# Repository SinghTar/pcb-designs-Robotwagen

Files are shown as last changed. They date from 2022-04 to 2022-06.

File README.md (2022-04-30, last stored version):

# PCB designs

## Linetrackerboard versie 1

Hieronder vindt u de schema en de pcb design van de linetrackerbordje.

### schema 

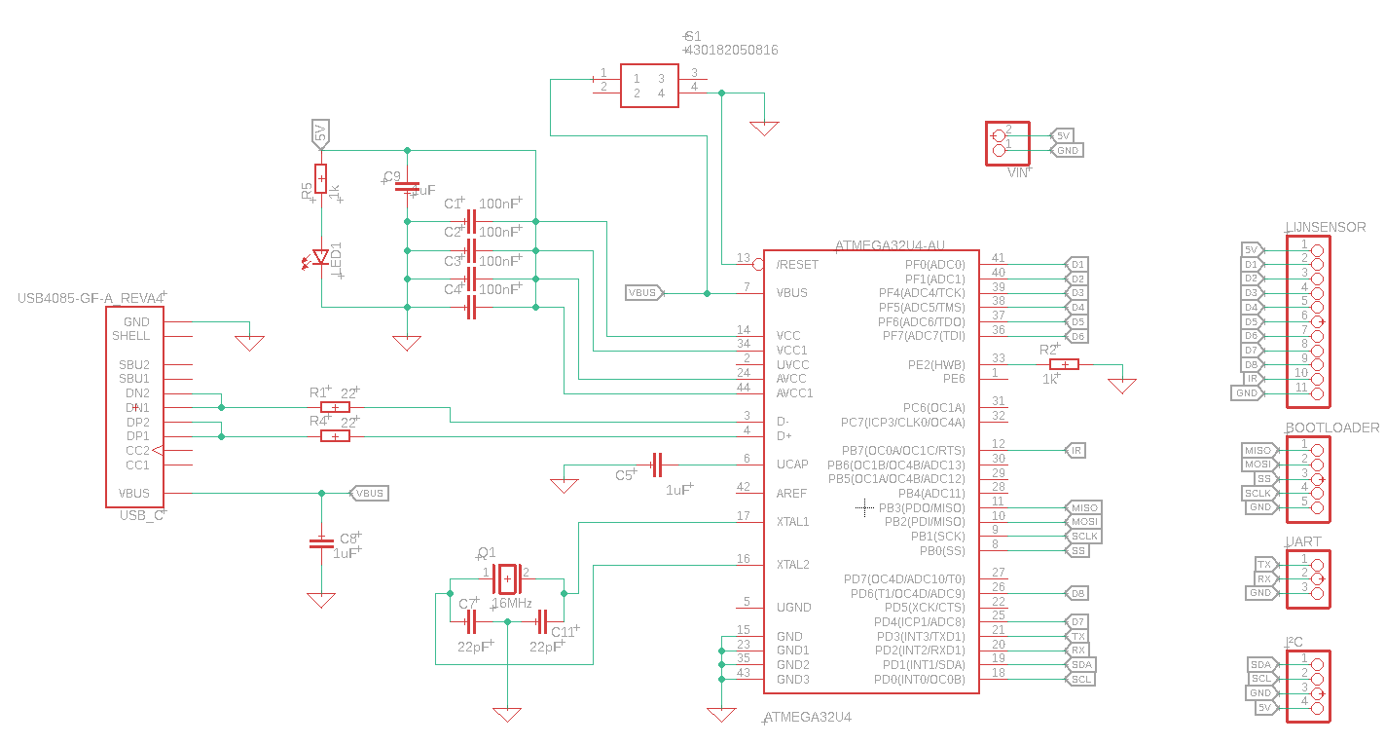
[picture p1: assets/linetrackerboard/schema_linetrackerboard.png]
schema linetrackerboard


### pcb

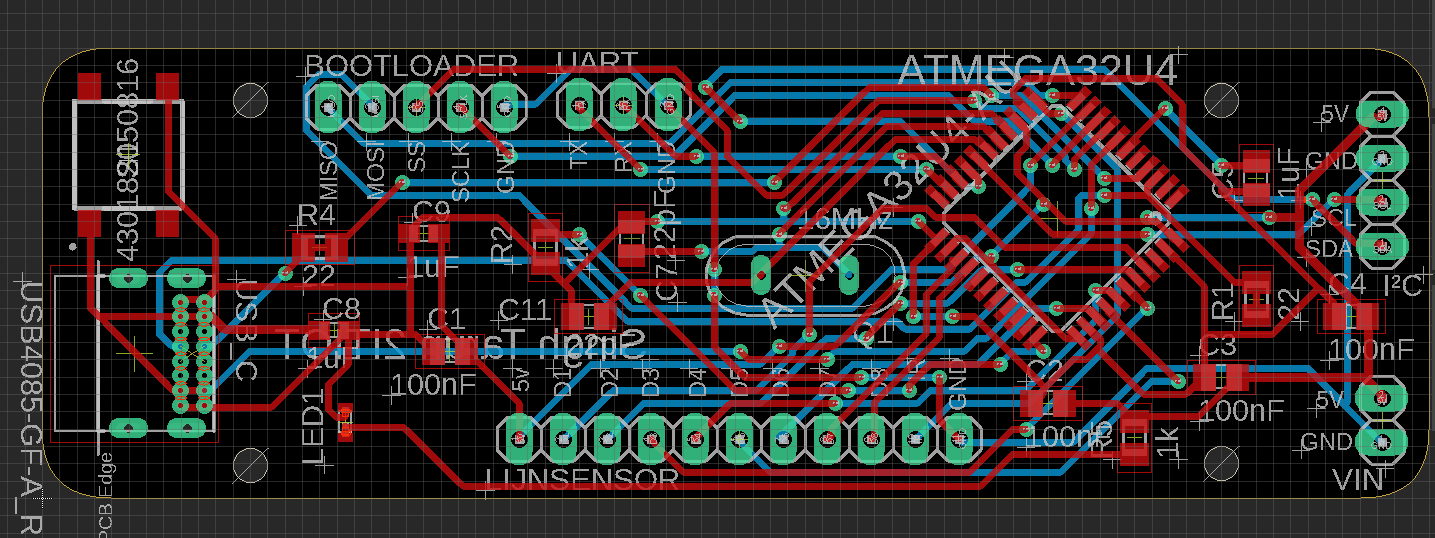
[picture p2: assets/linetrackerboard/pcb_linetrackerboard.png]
pcb linetrackerboard


### 3D design

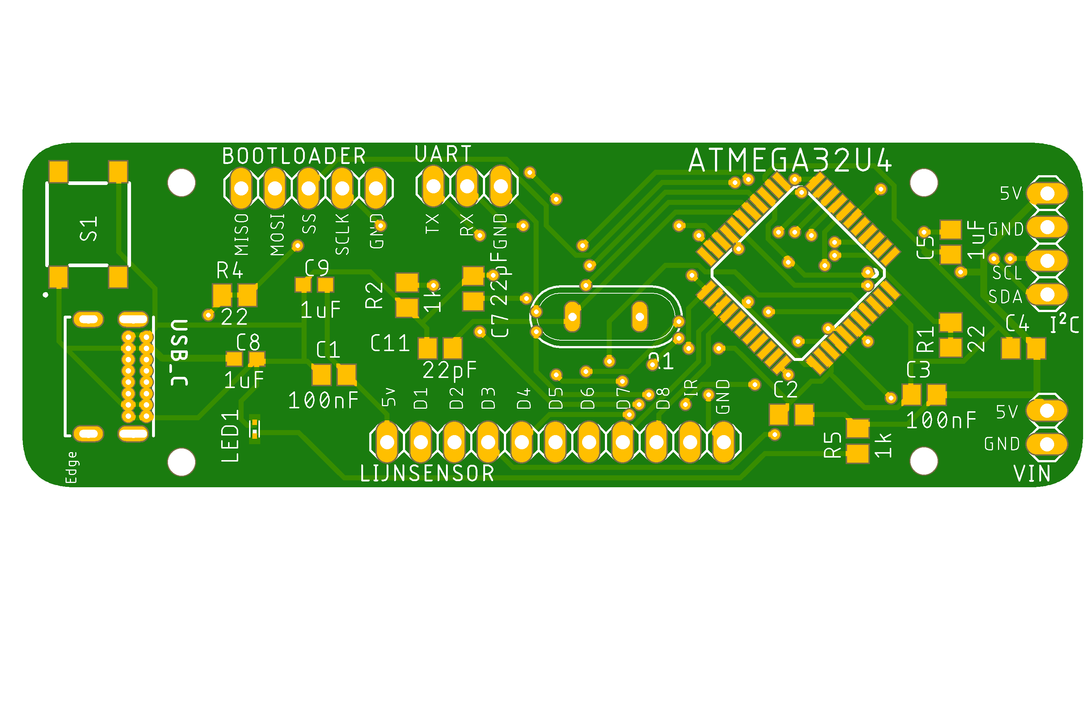
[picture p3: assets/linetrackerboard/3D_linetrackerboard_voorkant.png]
3D voorkant van linetrackerboard


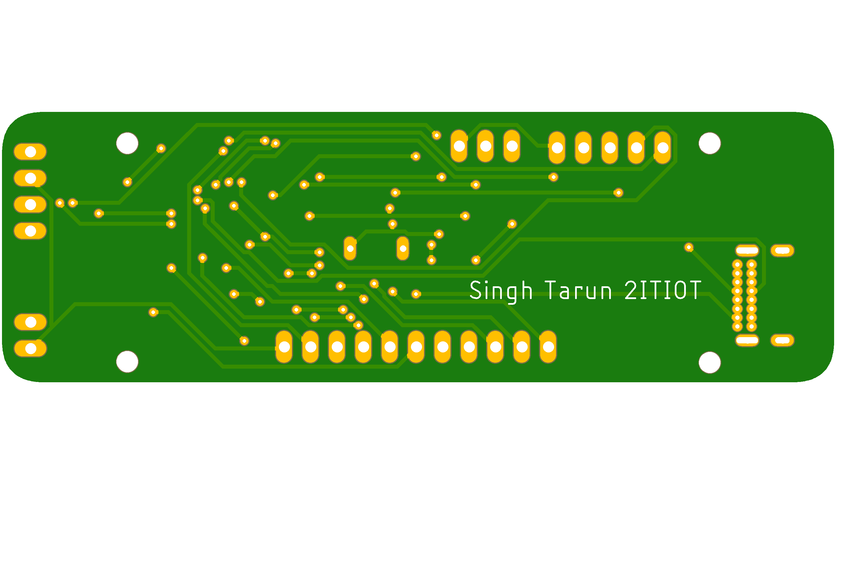
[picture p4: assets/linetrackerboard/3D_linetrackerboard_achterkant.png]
3D achterkant van linetrackerboard


## Motorsturing versie 1

Hieronder vindt u de schema en de pcb design van de motorsturing.

### schema 

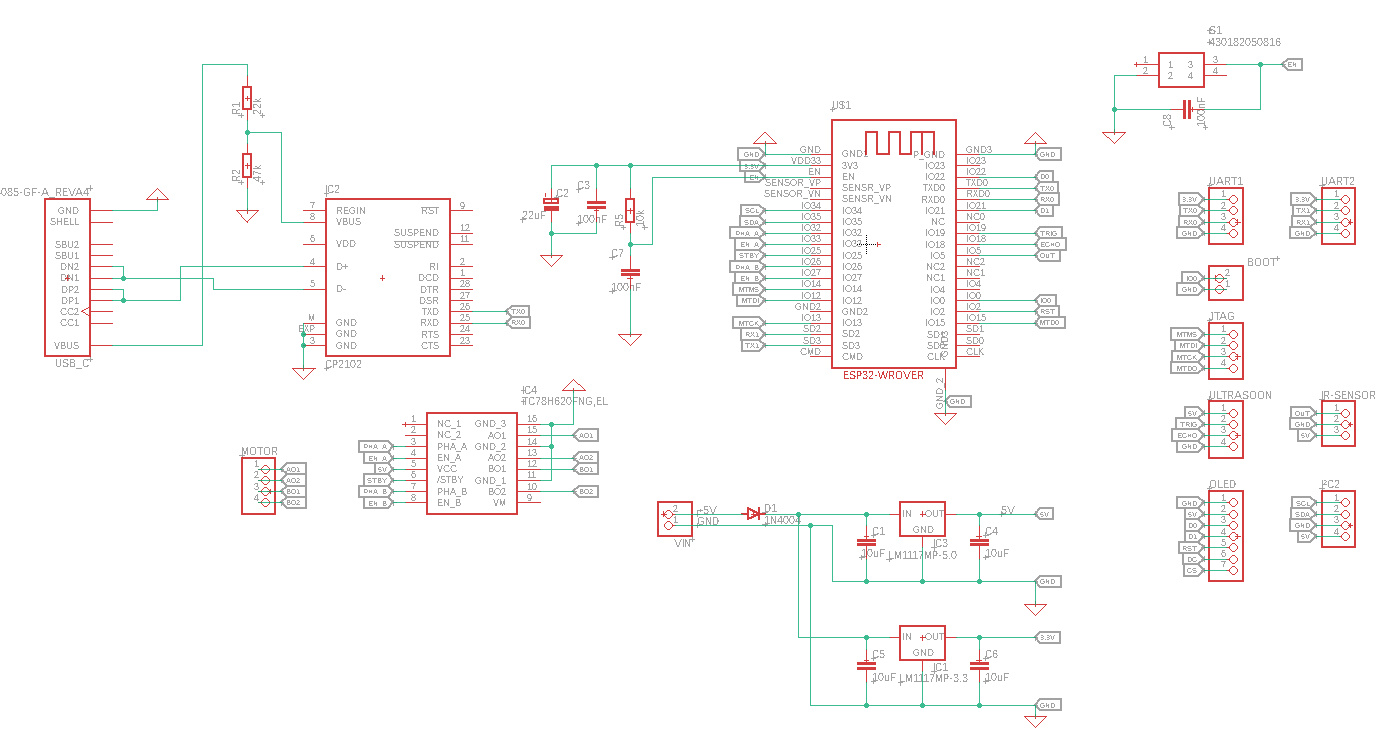
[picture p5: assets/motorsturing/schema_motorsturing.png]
schema motorsturing


### pcb

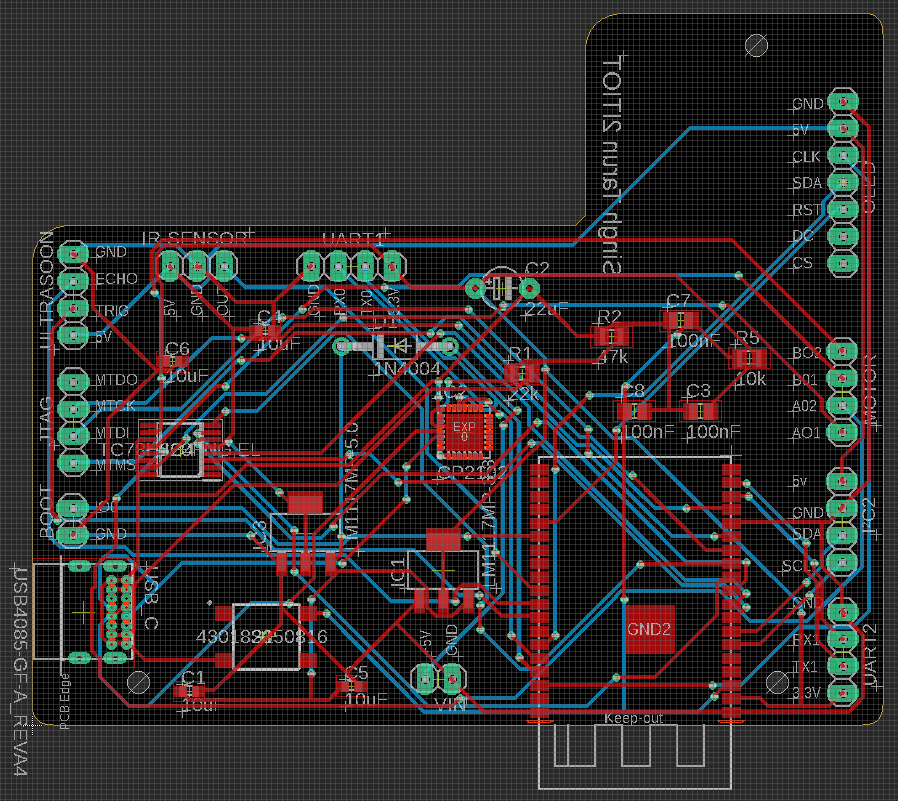
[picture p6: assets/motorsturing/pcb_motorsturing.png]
pcb motorsturing


### 3D design

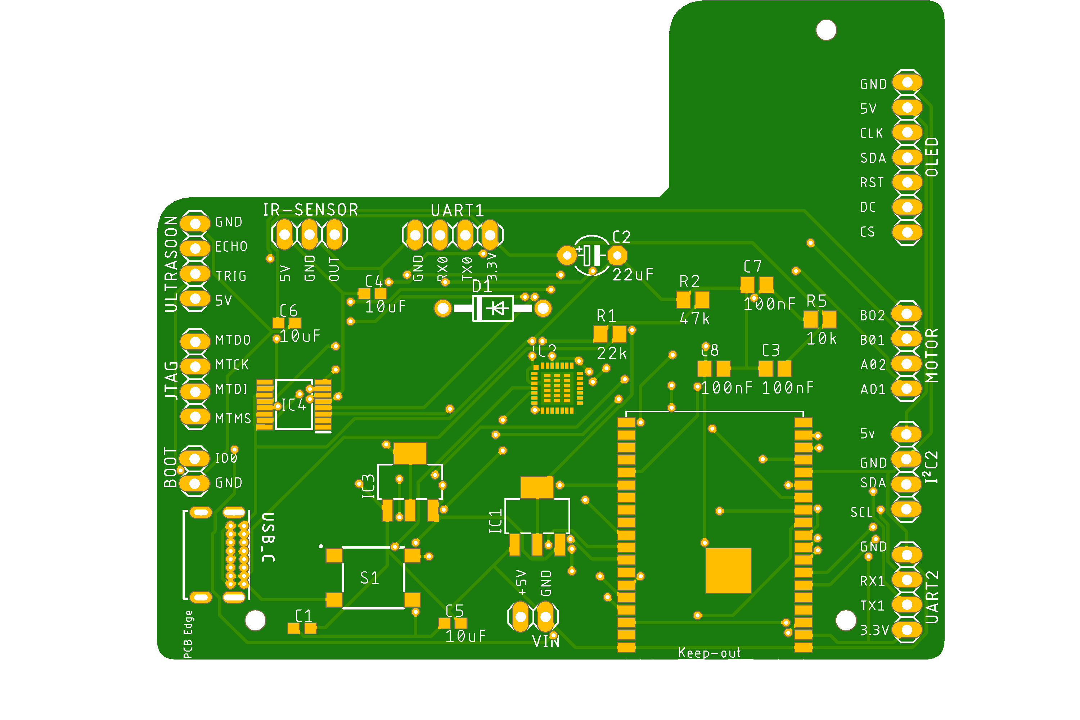
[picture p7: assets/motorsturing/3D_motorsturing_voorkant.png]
3D voorkant van motorsturing


3D achterkant van motorsturing

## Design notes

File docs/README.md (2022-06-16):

# PCB designs

## Linetrackerboard

### Versie 1

Hieronder vindt u de schema en de pcb design van de linetrackerbordje.

#### schema 

schema linetrackerboard

#### pcb

pcb linetrackerboard

#### 3D design

3D voorkant van linetrackerboard

3D achterkant van linetrackerboard

### Versie 2

Hieronder vindt u de schema en de pcb design van de linetrackerbordje.

#### schema 

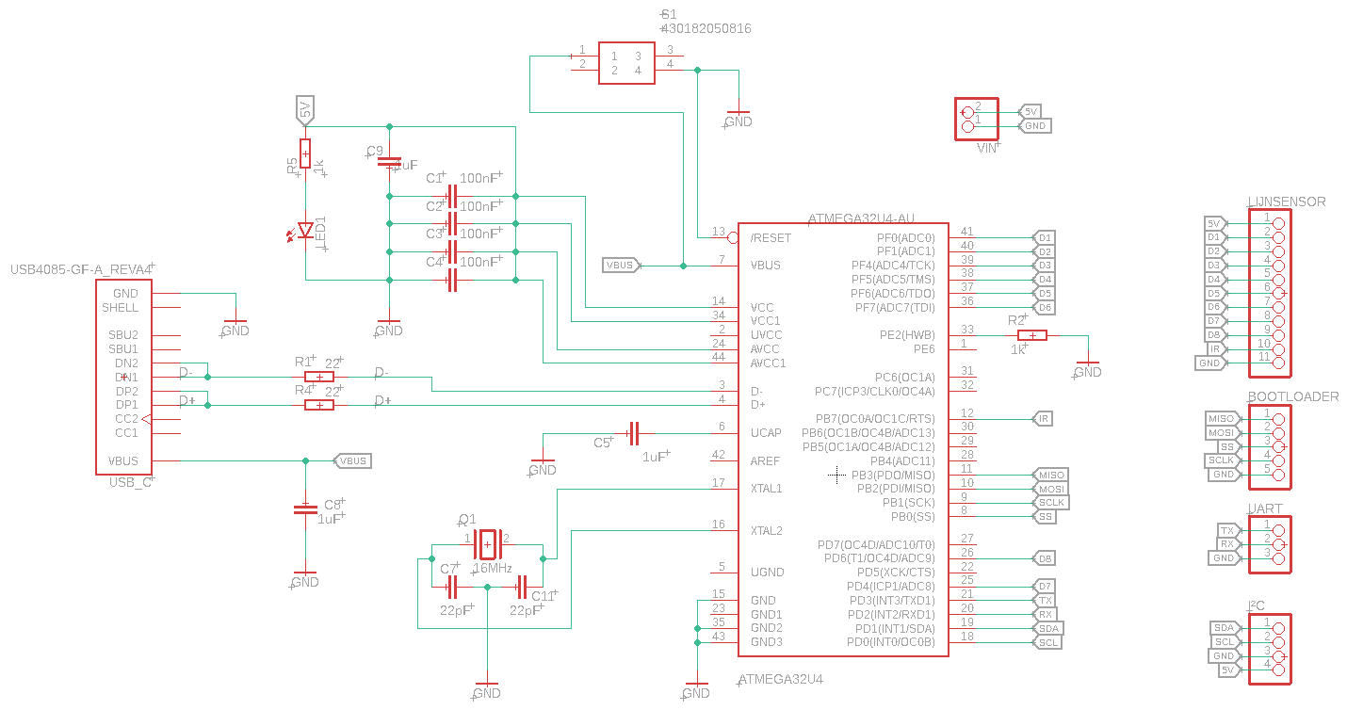
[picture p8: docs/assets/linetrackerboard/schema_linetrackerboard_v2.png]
schema linetrackerboard


#### pcb

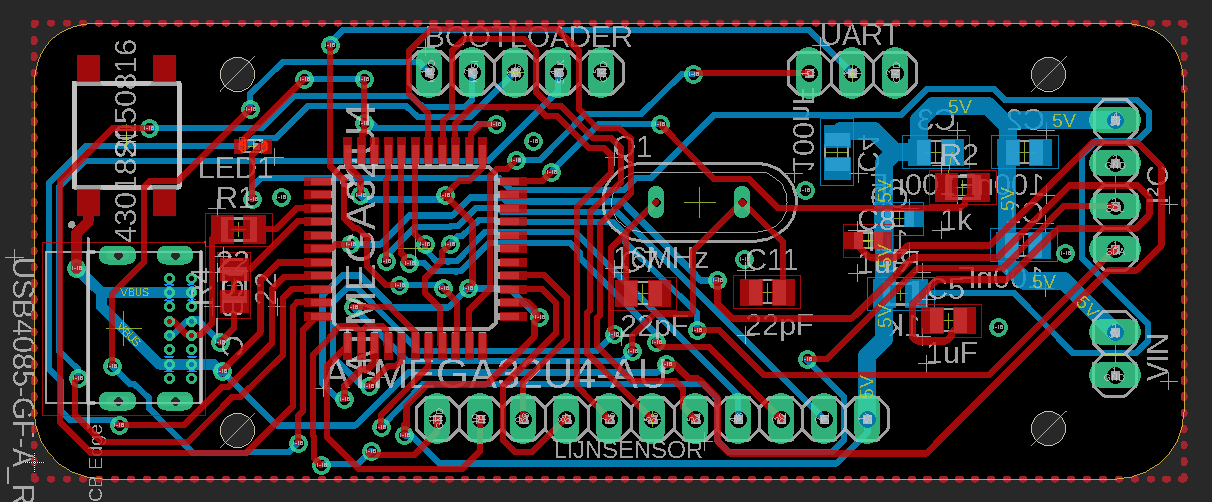
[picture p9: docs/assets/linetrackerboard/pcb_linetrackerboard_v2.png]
pcb linetrackerboard


#### 3D design

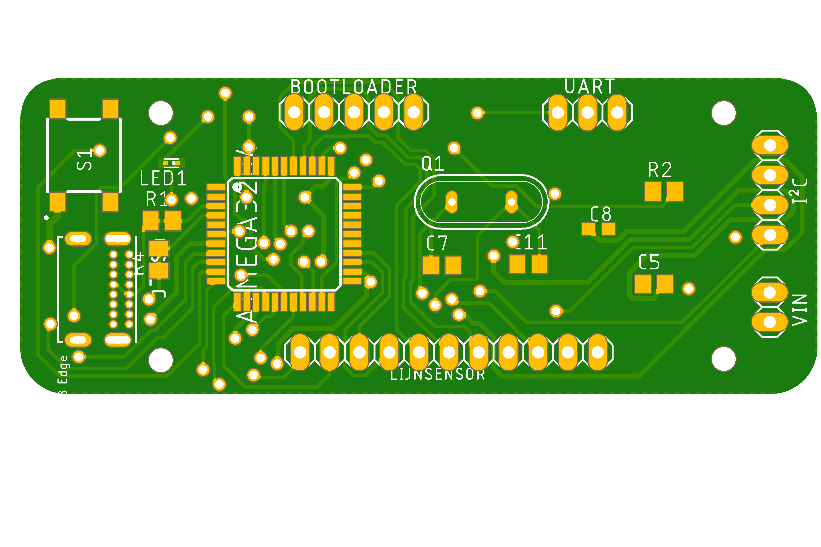
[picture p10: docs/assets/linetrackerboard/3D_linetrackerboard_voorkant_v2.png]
3D voorkant van linetrackerboard


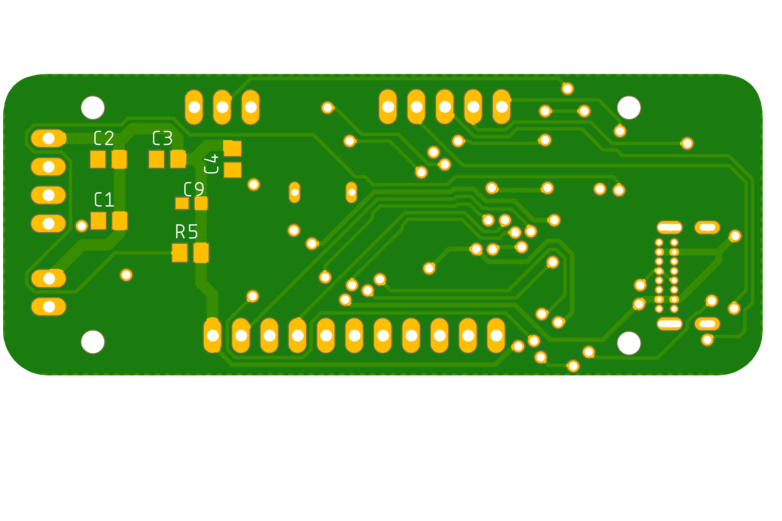
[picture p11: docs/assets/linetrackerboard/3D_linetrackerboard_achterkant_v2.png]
3D achterkant van linetrackerboard


## Motorsturing

### versie 1

Hieronder vindt u de schema en de pcb design van de motorsturing.

#### schema 

schema motorsturing

#### pcb

pcb motorsturing

#### 3D design

3D voorkant van motorsturing

3D achterkant van motorsturing

### versie 2

Hieronder vindt u de schema en de pcb design van de motorsturing.

#### schema 

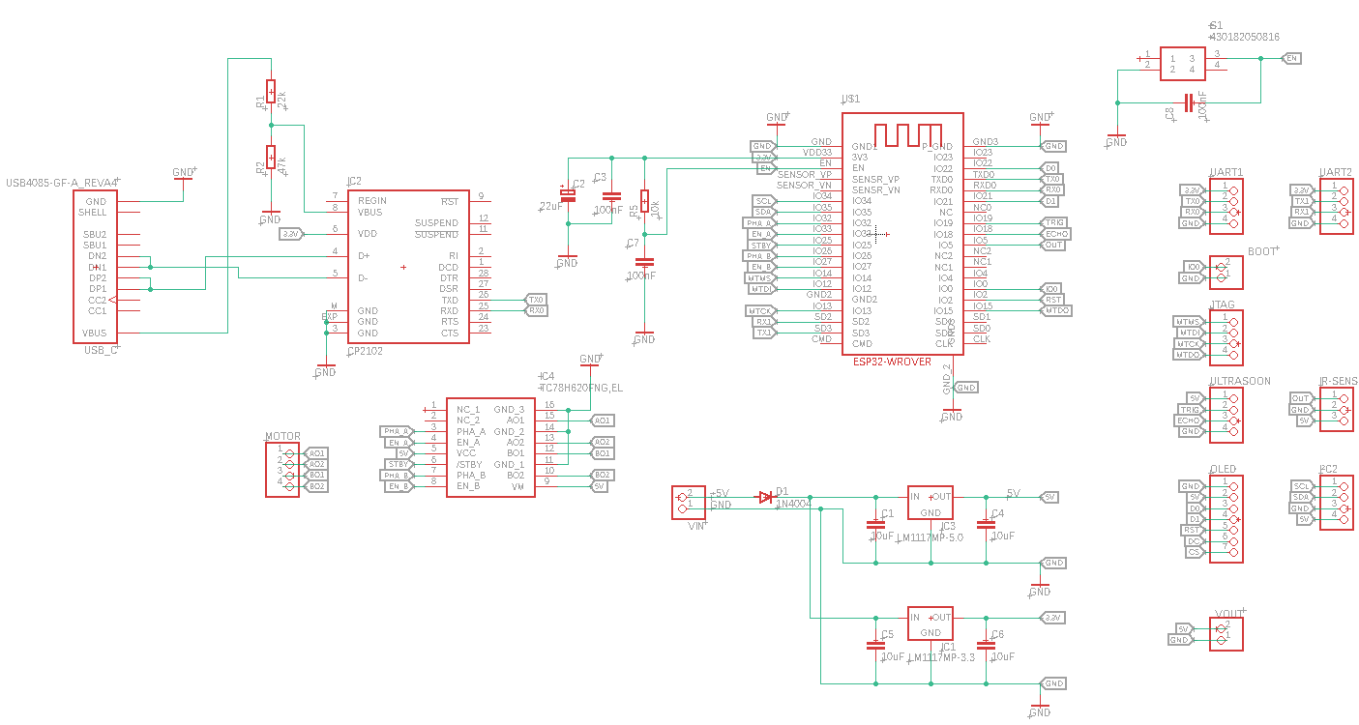
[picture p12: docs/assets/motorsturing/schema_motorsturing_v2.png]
schema motorsturing


#### pcb

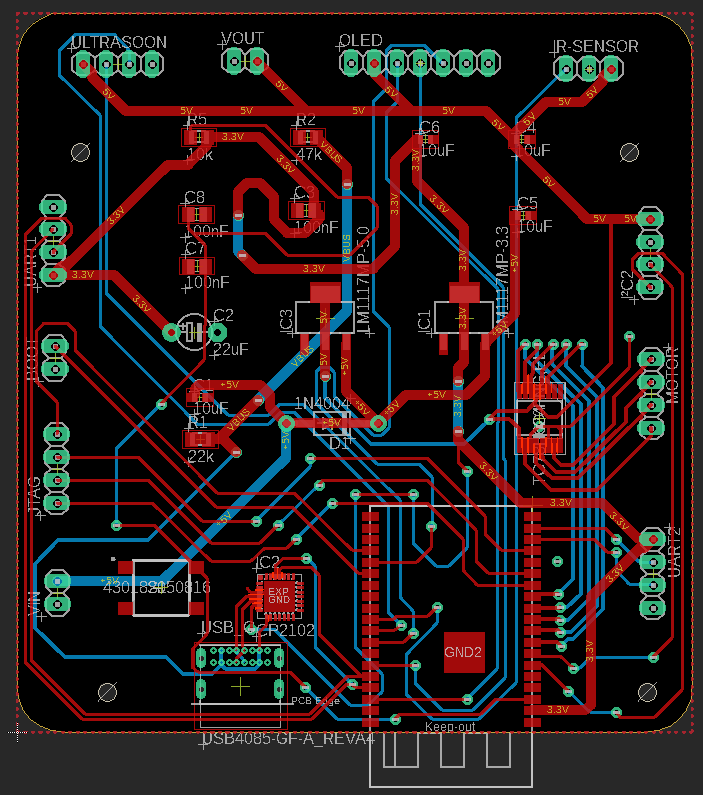
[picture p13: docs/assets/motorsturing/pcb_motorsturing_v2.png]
pcb motorsturing


#### 3D design

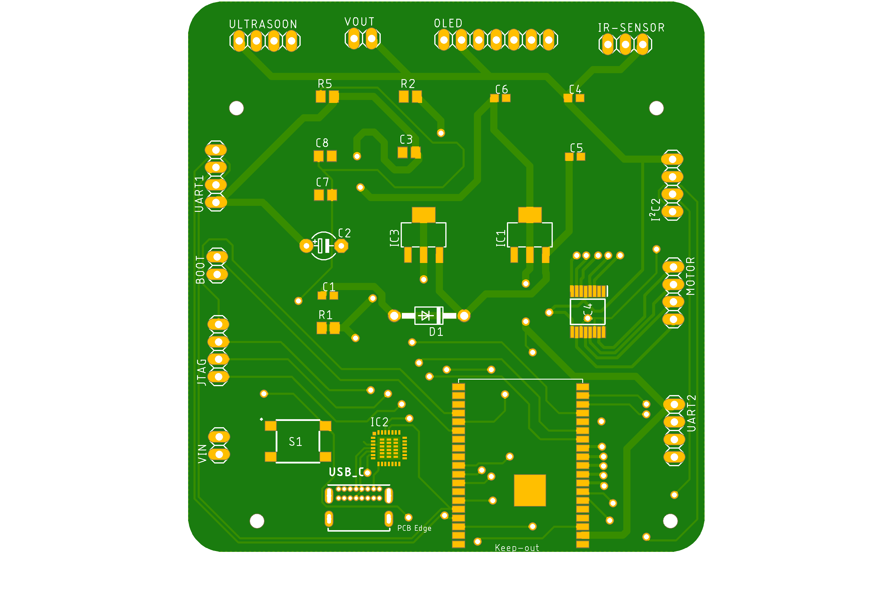
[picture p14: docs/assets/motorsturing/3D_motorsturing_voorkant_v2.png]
3D voorkant van motorsturing


3D achterkant van motorsturing

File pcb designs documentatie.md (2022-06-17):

# Externe link naar de pcb designs

[pcb designs robotwagen](https://singhtar.github.io/pcb-designs-Robotwagen/#/)

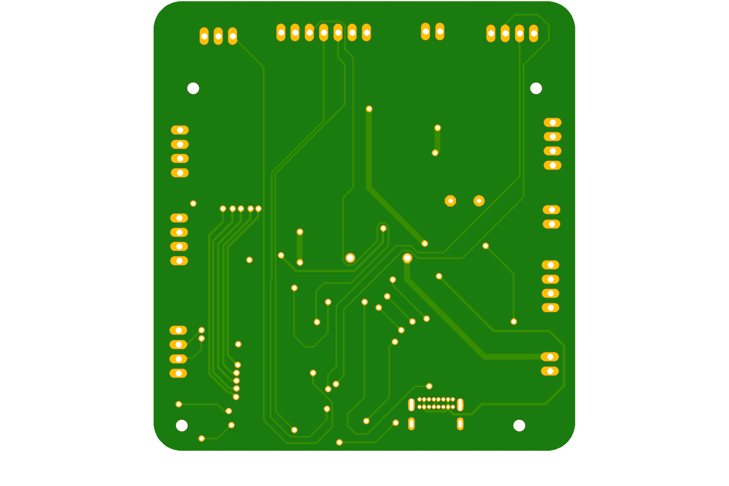
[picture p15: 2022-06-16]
docs/assets/motorsturing/3D_motorsturing_achterkant_v2.png

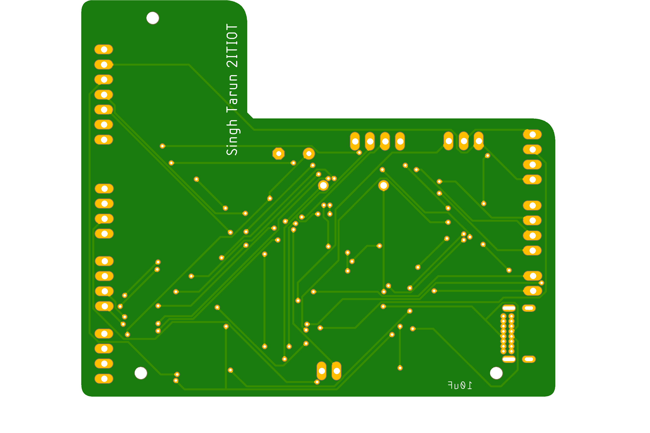
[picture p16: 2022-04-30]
docs/assets/motorsturing/3D_motorsturing_achterkant_v1.png

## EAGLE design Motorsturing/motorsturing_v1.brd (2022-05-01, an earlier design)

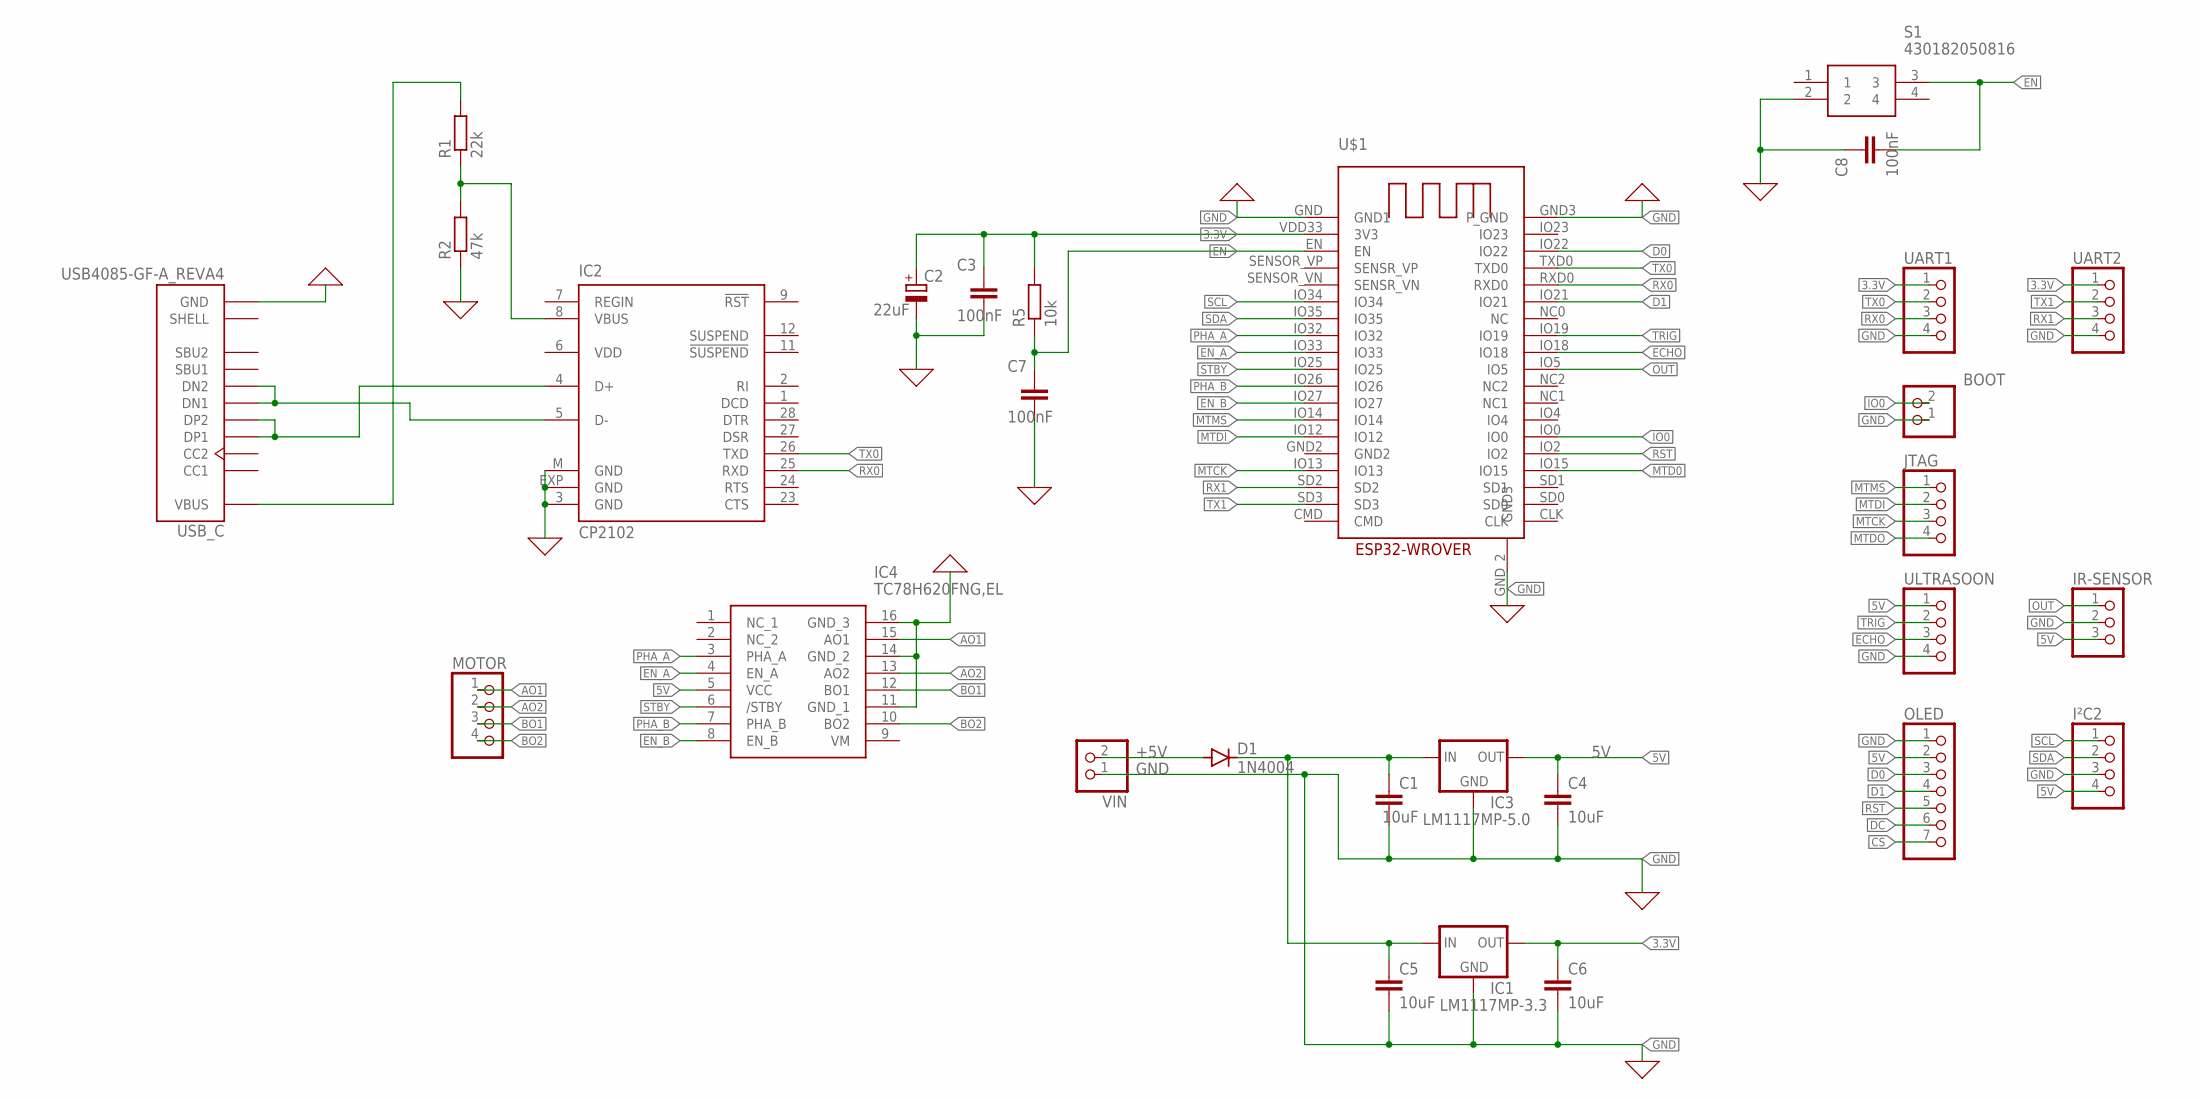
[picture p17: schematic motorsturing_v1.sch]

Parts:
BOOT: PINHD-1X2; 1X02
C1, C4, C5, C6: 10uF; C0603
C2: 22uF; E5-4
C3, C7, C8: 100nF; C0805
D1: 1N4004; DO41-10
IC1: LM1117MP-3.3; SOT223
IC2: CP2102; MLP28
IC3: LM1117MP-5.0; SOT223
IC4: TC78H620FNG,EL; SOP65P640X160-16N
IR-SENSOR: PINHD-1X3; 1X03
I²C2: PINHD-1X4; 1X04
JTAG: PINHD-1X4; 1X04
MOTOR: PINHD-1X4; 1X04
OLED: PINHD-1X7; 1X07
R1: 22k; M0805
R2: 47k; M0805
R5: 10k; M0805
S1: 430182050816; 430182070816
U$1: ESP32-WROVER
UART1, UART2: PINHD-1X4; 1X04
ULTRASOON: PINHD-1X4; 1X04
USB_C: USB4085-GF-A_REVA4; GCT_USB4085-GF-A_REVA4
VIN: PINHD-1X2; 1X02

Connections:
0: C2.-, C3.1, C7.1, C8.2, IC2.3 (GND), IC2.EXP (GND), IC2.M (GND), IC4.11 (GND_1), IC4.14 (GND_2), IC4.16 (GND_3), R2.1, S1.2, USB_C.A1 (GND), USB_C.A12 (GND), USB_C.B1 (GND), USB_C.B12 (GND)
3.3V: C2.+, C3.2, C6.1, IC1.2 (OUT), IC1.4 (OUT), R5.2, U$1.VDD33 (3V3), UART1.1, UART2.1
5V: C4.1, IC3.2 (OUT), IC3.4 (OUT), IC4.5 (VCC), IR-SENSOR.3, I²C2.4, OLED.2, ULTRASOON.1
+5V: D1.A, VIN.2
AO1: IC4.15 (AO1), MOTOR.1
AO2: IC4.13 (AO2), MOTOR.2
BO1: IC4.12 (BO1), MOTOR.3
BO2: IC4.10 (BO2), MOTOR.4
CS: OLED.7
D0: OLED.3, U$1.IO22
D1: OLED.4, U$1.IO21
DC: OLED.6
ECHO: U$1.IO18, ULTRASOON.3
EN: C7.2, C8.1, R5.1, S1.3, U$1.EN
EN_A: IC4.4 (EN_A), U$1.IO33
EN_B: IC4.8 (EN_B), U$1.IO27
GND: BOOT.1, C1.2, C4.2, C5.2, C6.2, IC1.1 (GND), IC3.1 (GND), IR-SENSOR.2, I²C2.3, OLED.1, U$1.GND (GND1), U$1.GND3 (P_GND), U$1.GND_2 (GND3), UART1.4, UART2.4, ULTRASOON.4, VIN.1
IO0: BOOT.2, U$1.IO0
MTCK: JTAG.3, U$1.IO13
MTD0: U$1.IO15
MTDI: JTAG.2, U$1.IO12
MTDO: JTAG.4
MTMS: JTAG.1, U$1.IO14
unnamed: IC2.5 (D-), USB_C.A7 (DN1), USB_C.B7 (DN2)
unnamed: IC2.4 (D+), USB_C.A6 (DP1), USB_C.B6 (DP2)
unnamed: R1.2, USB_C.A4 (VBUS), USB_C.A9 (VBUS), USB_C.B4 (VBUS), USB_C.B9 (VBUS)
unnamed: IC2.8 (VBUS), R1.1, R2.2
unnamed: C1.1, C5.1, D1.C, IC1.3 (IN), IC3.3 (IN)
OUT: IR-SENSOR.1, U$1.IO5
PHA_A: IC4.3 (PHA_A), U$1.IO32
PHA_B: IC4.7 (PHA_B), U$1.IO26
RST: OLED.5, U$1.IO2
RX0: IC2.25 (RXD), U$1.RXD0, UART1.3
RX1: U$1.SD2, UART2.3
SCL: I²C2.1, U$1.IO34
SDA: I²C2.2, U$1.IO35
STBY: IC4.6 (/STBY), U$1.IO25
TRIG: U$1.IO19, ULTRASOON.2
TX0: IC2.26 (TXD), U$1.TXD0, UART1.2
TX1: U$1.SD3, UART2.2
VDD: IC2.6 (VDD)

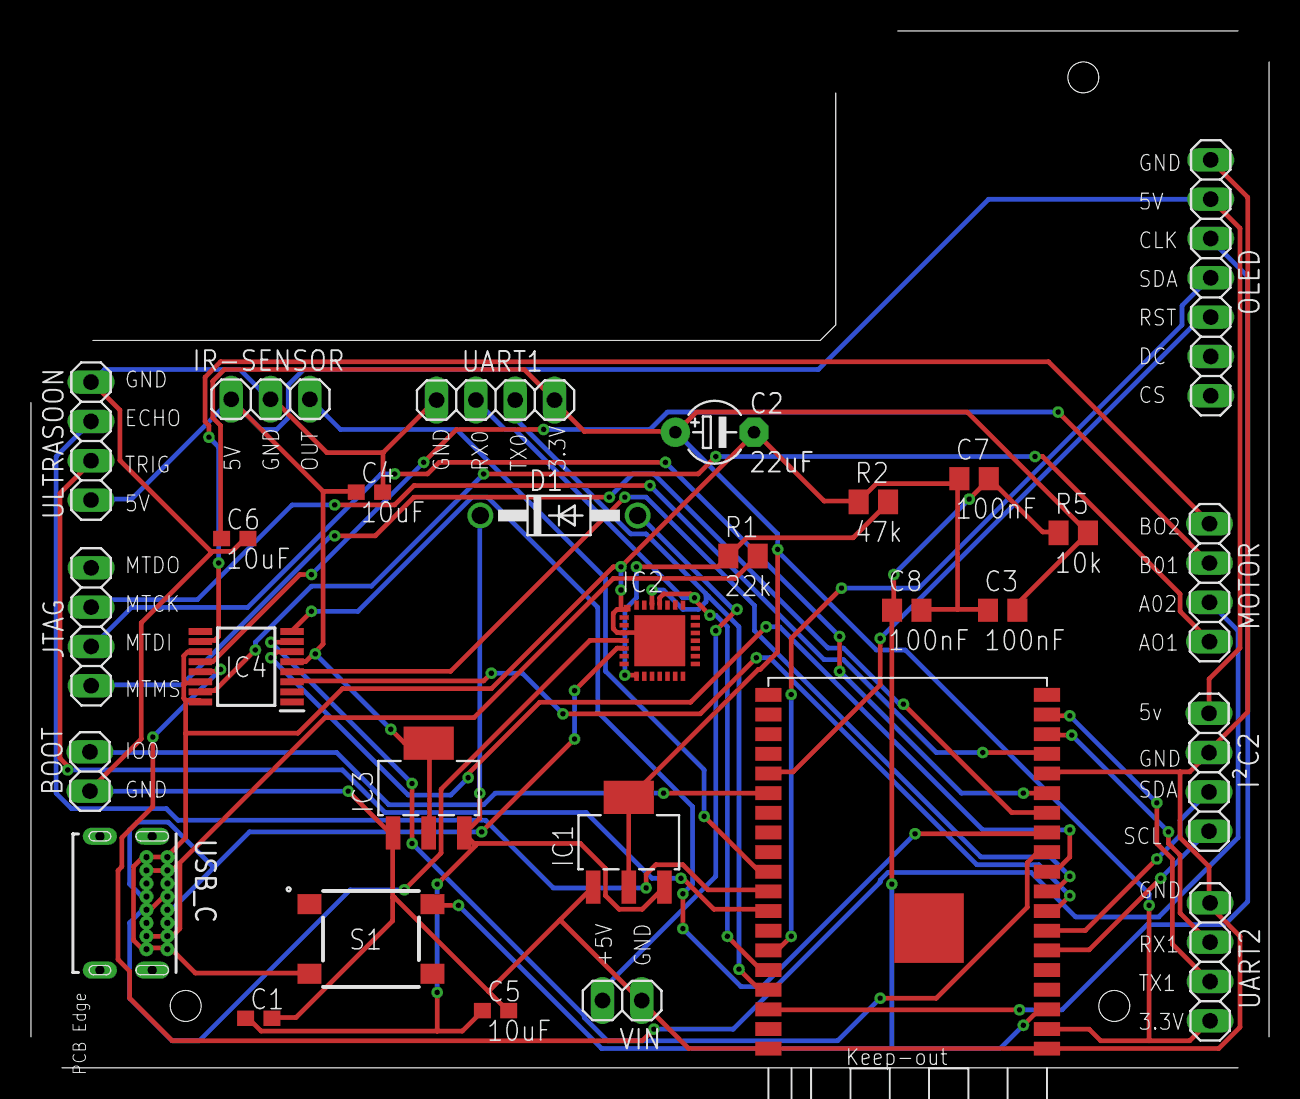
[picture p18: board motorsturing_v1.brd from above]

Board: 2 copper layers, 80.0 x 67.0 mm, 29 parts (0 on the bottom side), 36 nets.

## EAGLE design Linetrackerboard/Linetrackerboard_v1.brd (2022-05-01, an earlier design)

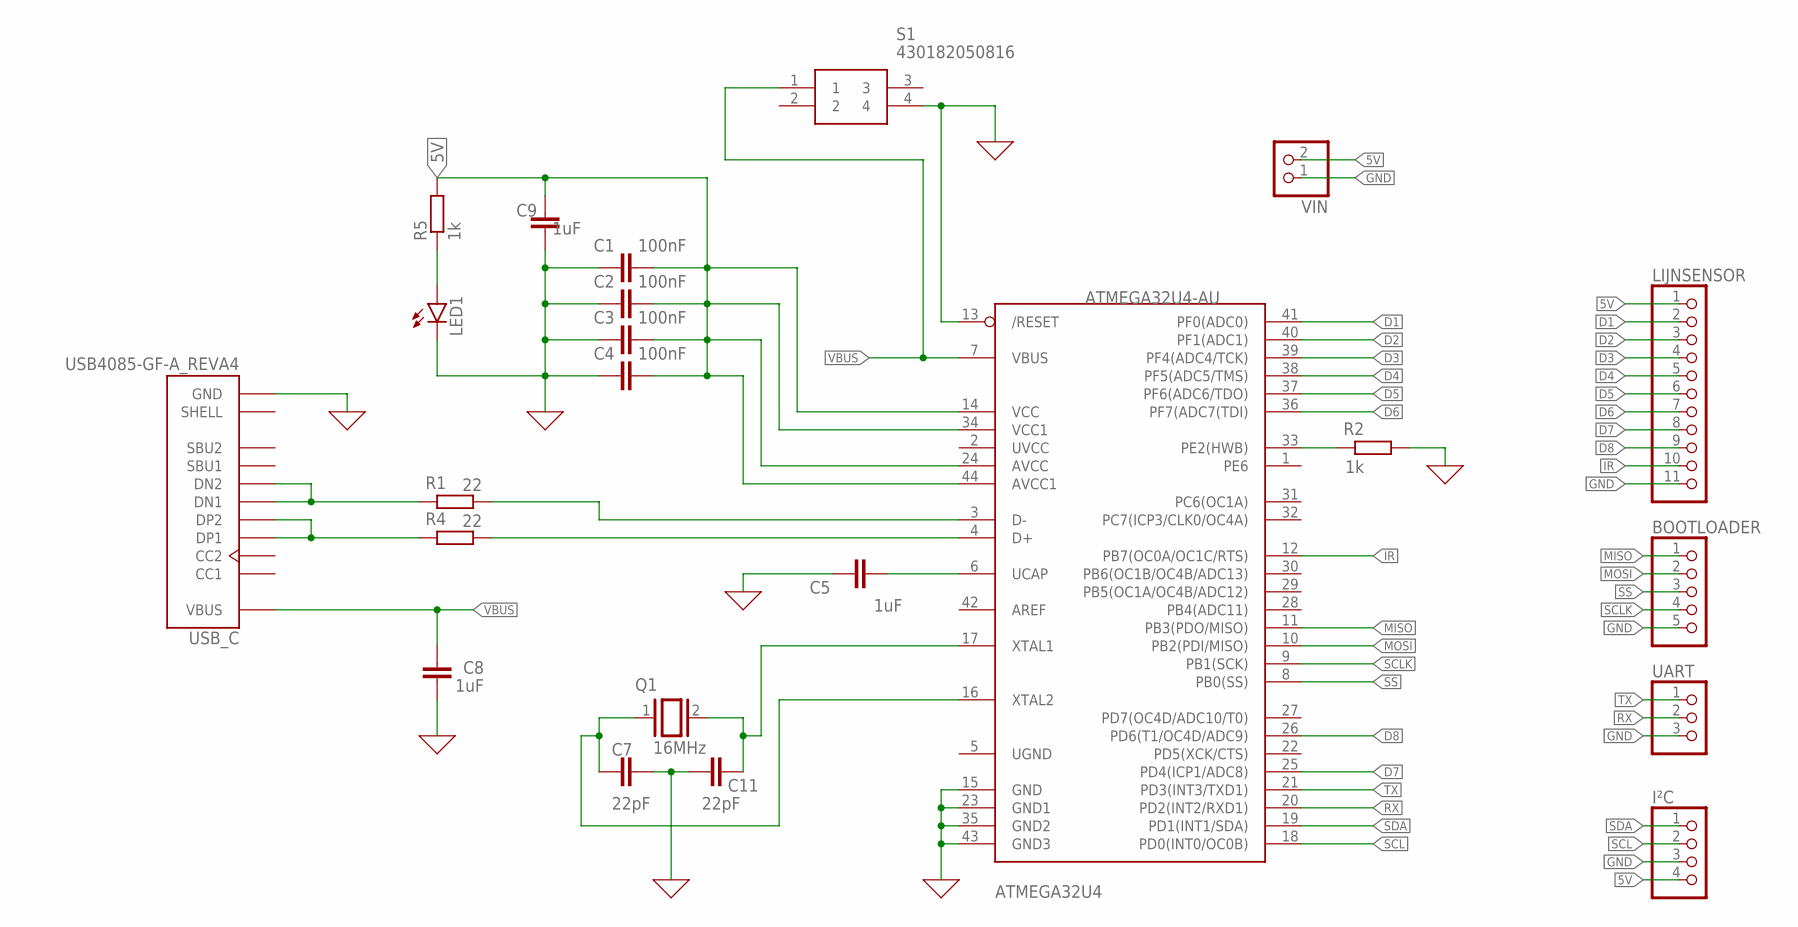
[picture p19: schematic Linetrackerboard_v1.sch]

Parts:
ATMEGA32U4: ATMEGA32U4-AU; TQFP44
BOOTLOADER: PINHD-1X5; 1X05
C1, C2, C3, C4: 100nF; C0805
C5: 1uF; C0805
C7, C11: 22pF; C0805
C8, C9: 1uF; C0603
I²C: PINHD-1X4; 1X04
LED1: LED; SMARTLED-TTW
LIJNSENSOR: PINHD-1X11; 1X11
Q1: 16MHz; QS
R1, R4: 22; M0805
R2, R5: 1k; M0805
S1: 430182050816; 430182070816
UART: PINHD-1X3; 1X03
USB_C: USB4085-GF-A_REVA4; GCT_USB4085-GF-A_REVA4
VIN: PINHD-1X2; 1X02

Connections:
0: ATMEGA32U4.13 (/RESET), ATMEGA32U4.15 (GND), ATMEGA32U4.23 (GND1), ATMEGA32U4.35 (GND2), ATMEGA32U4.43 (GND3), C1.1, C2.1, C3.1, C4.1, C5.1, C7.2, C8.2, C9.1, C11.1, LED1.C@1 (C), R2.1, S1.4, USB_C.A1 (GND), USB_C.A12 (GND), USB_C.B1 (GND), USB_C.B12 (GND)
5V: ATMEGA32U4.14 (VCC), ATMEGA32U4.24 (AVCC), ATMEGA32U4.34 (VCC1), ATMEGA32U4.44 (AVCC1), C1.2, C2.2, C3.2, C4.2, C9.2, I²C.4, LIJNSENSOR.1, R5.2, VIN.2
D1: ATMEGA32U4.41 (PF0(ADC0)), LIJNSENSOR.2
D2: ATMEGA32U4.40 (PF1(ADC1)), LIJNSENSOR.3
D3: ATMEGA32U4.39 (PF4(ADC4/TCK)), LIJNSENSOR.4
D4: ATMEGA32U4.38 (PF5(ADC5/TMS)), LIJNSENSOR.5
D5: ATMEGA32U4.37 (PF6(ADC6/TDO)), LIJNSENSOR.6
D6: ATMEGA32U4.36 (PF7(ADC7(TDI)), LIJNSENSOR.7
D7: ATMEGA32U4.25 (PD4(ICP1/ADC8)), LIJNSENSOR.8
D8: ATMEGA32U4.26 (PD6(T1/OC4D/ADC9)), LIJNSENSOR.9
D+: ATMEGA32U4.4 (D+), R4.1, R4.2, USB_C.A6 (DP1), USB_C.B6 (DP2)
D-: ATMEGA32U4.3 (D-), R1.1, R1.2, USB_C.A7 (DN1), USB_C.B7 (DN2)
GND: BOOTLOADER.5, I²C.3, LIJNSENSOR.11, UART.3, VIN.1
IR: ATMEGA32U4.12 (PB7(OC0A/OC1C/RTS)), LIJNSENSOR.10
MISO: ATMEGA32U4.11 (PB3(PDO/MISO)), BOOTLOADER.1
MOSI: ATMEGA32U4.10 (PB2(PDI/MISO)), BOOTLOADER.2
unnamed: ATMEGA32U4.17 (XTAL1), C11.2, Q1.2
unnamed: ATMEGA32U4.16 (XTAL2), C7.1, Q1.1
unnamed: ATMEGA32U4.33 (PE2(HWB)), R2.2
unnamed: LED1.A@1 (A), R5.1
unnamed: ATMEGA32U4.6 (UCAP), C5.2
RX: ATMEGA32U4.20 (PD2(INT2/RXD1)), UART.2
SCL: ATMEGA32U4.18 (PD0(INT0/OC0B)), I²C.2
SCLK: ATMEGA32U4.9 (PB1(SCK)), BOOTLOADER.4
SDA: ATMEGA32U4.19 (PD1(INT1/SDA)), I²C.1
SS: ATMEGA32U4.8 (PB0(SS)), BOOTLOADER.3
TX: ATMEGA32U4.21 (PD3(INT3/TXD1)), UART.1
VBUS: ATMEGA32U4.7 (VBUS), C8.1, S1.1, USB_C.A4 (VBUS), USB_C.A9 (VBUS), USB_C.B4 (VBUS), USB_C.B9 (VBUS)

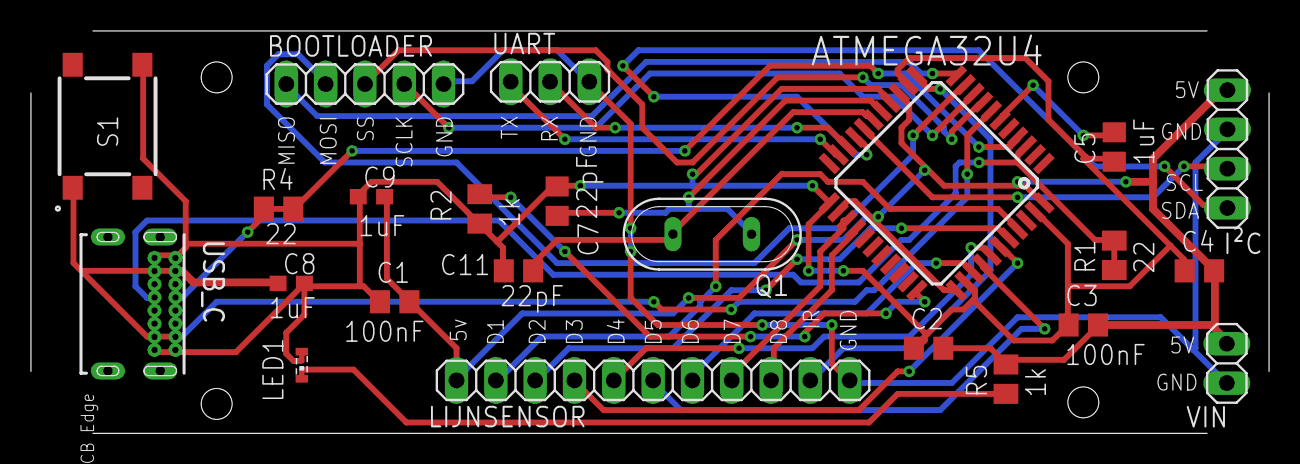
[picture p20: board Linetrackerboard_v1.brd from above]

Board: 2 copper layers, 80.0 x 26.0 mm, 23 parts (0 on the bottom side), 28 nets.

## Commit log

2022-04-30 new file: .nojekyll modified: README.md new file: assets/linetrackerboard/3D_linetrackerboard_achterkant.png new file: assets/linetrackerboard/3D_linetrackerboard_voorkant.png new file: assets/linetr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
2022-05-01 new file: Linetrackerboard/Linetrackerboard.brd new file: Linetrackerboard/Linetrackerboard.sch new file: Motorsturing/motorsturing.brd new file: Motorsturing/motorsturing.sch
    [Linetrackerboard.brd, Linetrackerboard.sch, motorsturing.brd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]
2022-06-17 Create pcb designs robotwagen.md
2022-06-17 Rename pcb designs robotwagen.md to pcb designs robotwagen (documentatie).md
2022-06-17 Rename pcb designs robotwagen (documentatie).md to pcb designs documentatie.md
2022-06-17 Update pcb designs documentatie.md
